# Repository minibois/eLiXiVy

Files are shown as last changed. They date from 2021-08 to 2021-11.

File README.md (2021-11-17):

# mini-eLiXiVy
## Repository for the mini-eLiXiVy, a 65% mechanical keyboard PCB, suitable for ISO and ANSI layouts, USB Type C and a (tactile) rotary encoder.
 This PCB is compatible with KBDFans' 65% low profile case/plate and Cherry MX(-like) keyswitches.
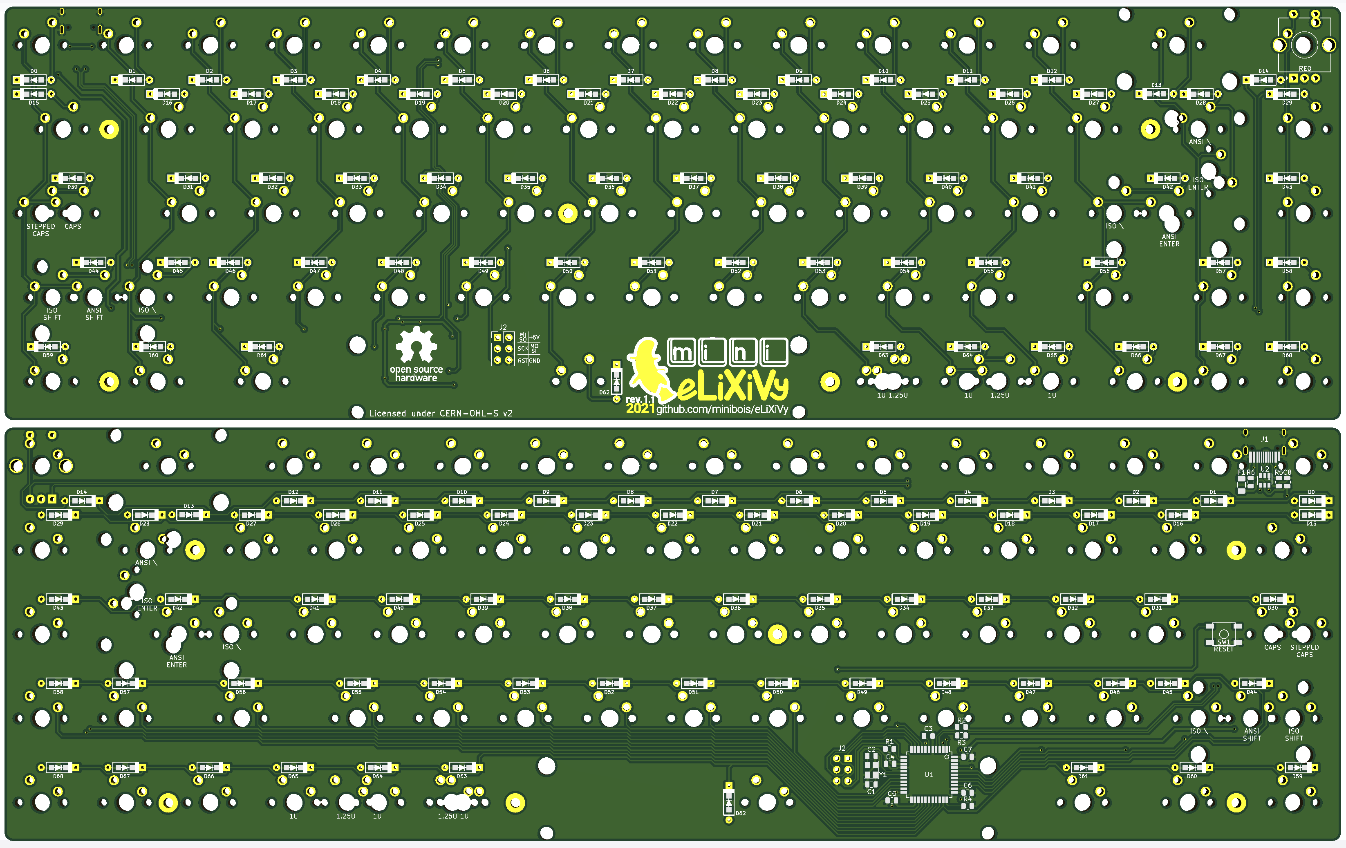
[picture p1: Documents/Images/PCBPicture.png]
mini-eLiXiVy-PCB-Render

 _Render of the front and back of the PCB respectively_

 << [License](https://github.com/minibois/eLiXiVy/blob/master/LICENSE/LICENSE.txt) || [Assembly Guide](https://github.com/minibois/eLiXiVy/blob/master/Documents/Assembly%20Guide.pdf) || BOM ([Octoparts](https://octopart.com/bom-tool/allQRgda)) / ([.txt](https://github.com/minibois/eLiXiVy/blob/master/Documents/BOM.txt)) / ([.xlsx](https://github.com/minibois/eLiXiVy/blob/master/Documents/BOM.xlsx)) || [Supported layouts](https://raw.githubusercontent.com/minibois/eLiXiVy/master/Documents/Layouts/layouts.png) || Schematic ([.pdf](https://github.com/minibois/eLiXiVy/blob/master/Documents/Schematic.pdf)) / ([.sch](https://github.com/minibois/eLiXiVy/blob/master/mini-eLiXiVy.sch)) || PCB ([.pdf](https://github.com/minibois/eLiXiVy/blob/master/Documents/PCB.pdf)) / ([.kicad_pcb](https://github.com/minibois/eLiXiVy/blob/master/mini-eLiXiVy.kicad_pcb)) >>

 The PCB and schematic are licensed under CERN-OHL-S v2, full license details can be found here: https://github.com/minibois/eLiXiVy/blob/master/Documents/LICENSE.txt.

### The compatible layouts for this PCB are as follows:
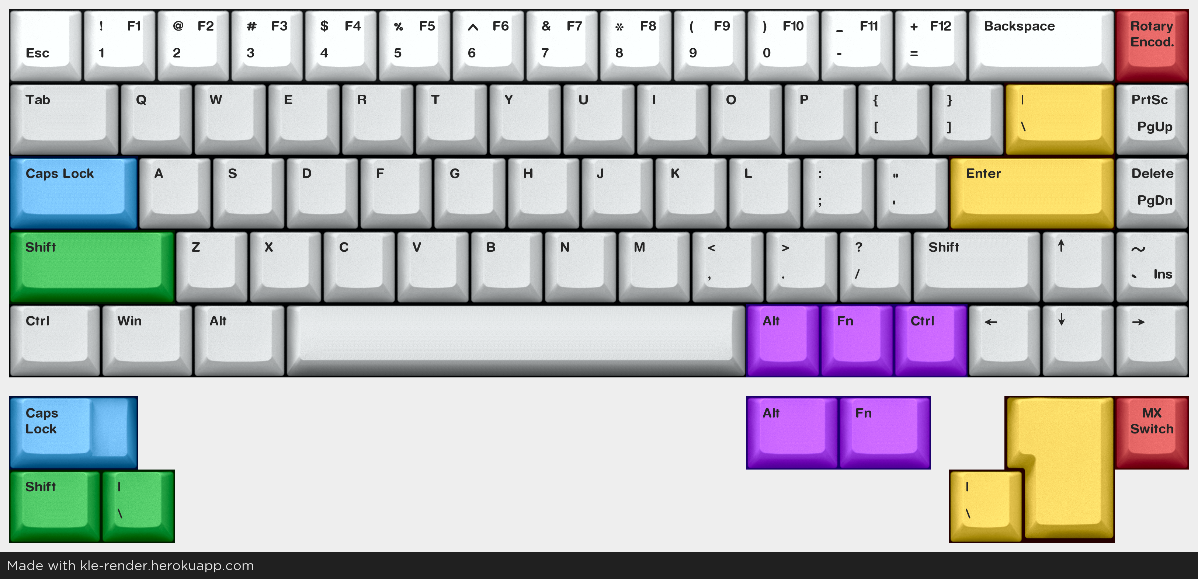
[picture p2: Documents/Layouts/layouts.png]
mini-eLiXiVy-Layouts-Supported

 _The mini-eLiXiVy supports between 66 and 69 switches, depending on the layout chosen._
 In the top right of the keyboard you can either use an MX-like keyswitch or a rotary encoder with switch (see the BOM for a verified compatible option).
 
 While the the bill of materials mentions tested compatible components, substitutes may be available, should these components become difficult to obtain. Should you choose alternatives, you do so at your own risk. I can only vouch for the compability of the listed components.

## Libraries used in this project (most of them adapted to this project):
 * That-Canadian's KiCad_labs (for the D-SOD123_axial-dual): https://github.com/That-Canadian/KiCad_Libs
 * Type-C.Pretty: https://github.com/ai03-2725/Type-C.pretty
 * MX_Alps_Hybrid: https://github.com/ai03-2725/MX_Alps_Hybrid
 * random-keyboard-parts (for a reset switch): https://github.com/ai03-2725/random-keyboard-parts.pretty

### This PCB file and schematic is provided - as per CERN-OHL-S v2 section 6 - _without any warranty_ (implied or otherwise). https://ohwr.org/cern_ohl_s_v2.pdf
### The assembly guide is provided under the CC BY-SA 4.0, without any warranty (implied or otherwise): https://creativecommons.org/licenses/by-sa/4.0/legalcode

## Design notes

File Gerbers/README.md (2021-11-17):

rev.1a is the alpha version of the project, included for completeness sake.
rev.1 had some minor changes
rev.1.1 (or newer) is recommended for assembly

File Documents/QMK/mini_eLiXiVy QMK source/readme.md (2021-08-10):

# mini_eLiXiVy

mini_eLiXiVy

*A short description of the keyboard/project*

* Keyboard Maintainer: [minibois](https://github.com/minibois)
* Hardware Supported: mini_eLiXiVy PCB, KBDFans' 65% plate and case, PCB mount stabilizers
* Hardware Availability: PCB: https://github.com/minibois, BOM: https://octopart.com/bom-tool/allQRgda

Make example for this keyboard (after setting up your build environment):

    make mini_eLiXiVy:default

Flashing example for this keyboard:

    make mini_eLiXiVy:default:flash

See the [build environment setup](https://docs.qmk.fm/#/getting_started_build_tools) and the [make instructions](https://docs.qmk.fm/#/getting_started_make_guide) for more information. 
Brand new to QMK? Start with our [Complete Newbs Guide](https://docs.qmk.fm/#/newbs).

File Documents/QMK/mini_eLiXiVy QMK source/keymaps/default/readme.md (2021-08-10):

# The default keymap for mini_eLiXiVy
This is an ANSI keymap, with three 1u modifiers between the spacebar/arrow keys and a rotary encoder.

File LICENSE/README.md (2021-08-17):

# Copyright minibois 2021.

This source describes Open Hardware and is licensed under the CERN-OHL-S v2.
You may redistribute and modify this source and make products using it under the terms of the CERN-OHL-S v2 (https://ohwr.org/cern_ohl_s_v2.txt).
This source is distributed WITHOUT ANY EXPRESS OR IMPLIED WARRANTY, INCLUDING OF MERCHANTABILITY, SATISFACTORY QUALITY AND FITNESS FOR A PARTICULAR PURPOSE.
Please see the CERN-OHL-S v2 for applicable conditions.

As per CERN-OHL-S v2 section 4, should you produce hardware based on this source, you must where practicable maintain the Source Location visible on the keyboard PCB or on other products you make using this source.
Source location: https://github.com/minibois/eLiXiVy/
When changes have been made, please update ../Documents/CHANGES.txt accordingly.

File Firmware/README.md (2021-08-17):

# mini eLiXiVy firmware files
Depending on the layout chosen for the eLiXiVy, a different firmware version may be suitable.
This folder has three firmware types available: default, ansi and iso.
As a reminder, the eLiXiVy supports these layouts:
mini-eLiXiVy-Layouts-Supported

## Default
This is a barebones firmware with an ansi layout:
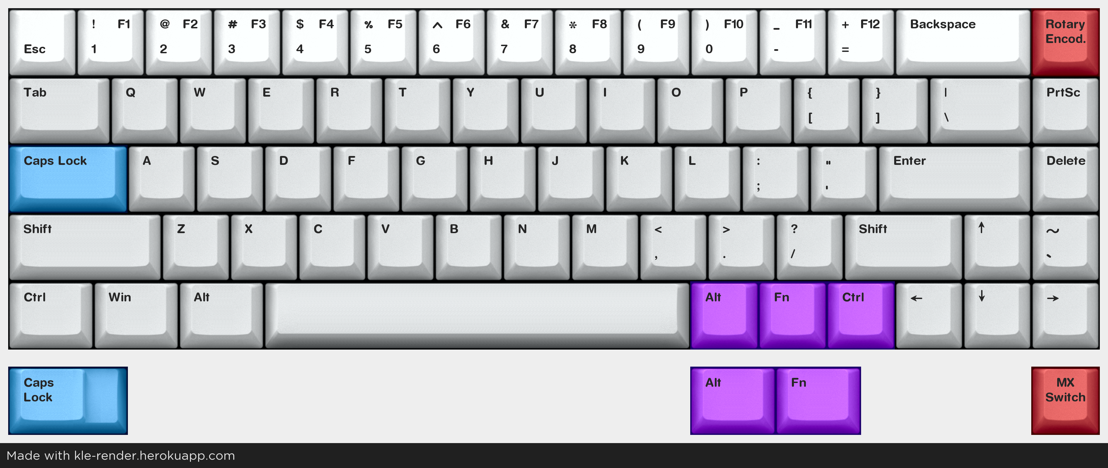
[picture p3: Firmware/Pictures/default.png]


## ansi
This is like the default firmware, but with some added functionality under the Function layer
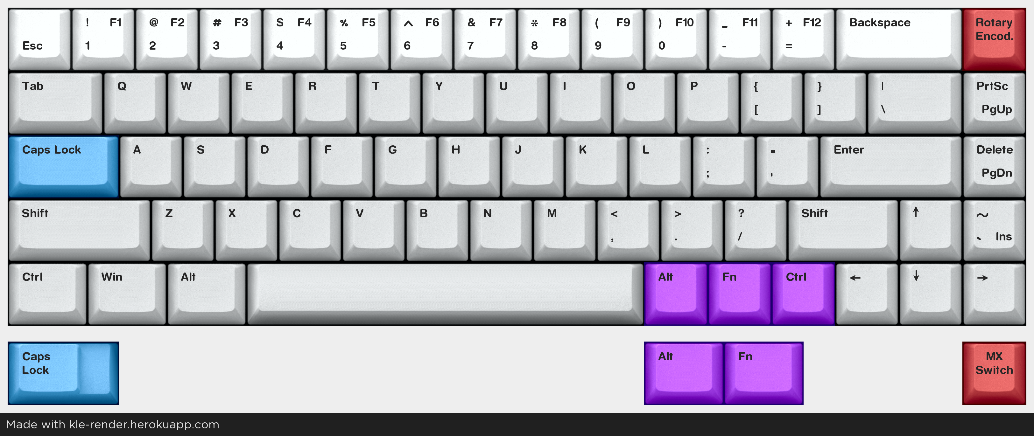
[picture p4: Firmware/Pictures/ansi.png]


## iso
While the default and ansi firmware are both using the ansi layout, the iso firmware uses the iso layout, with its backslash key on the left and iso (upside-down L) Enter.
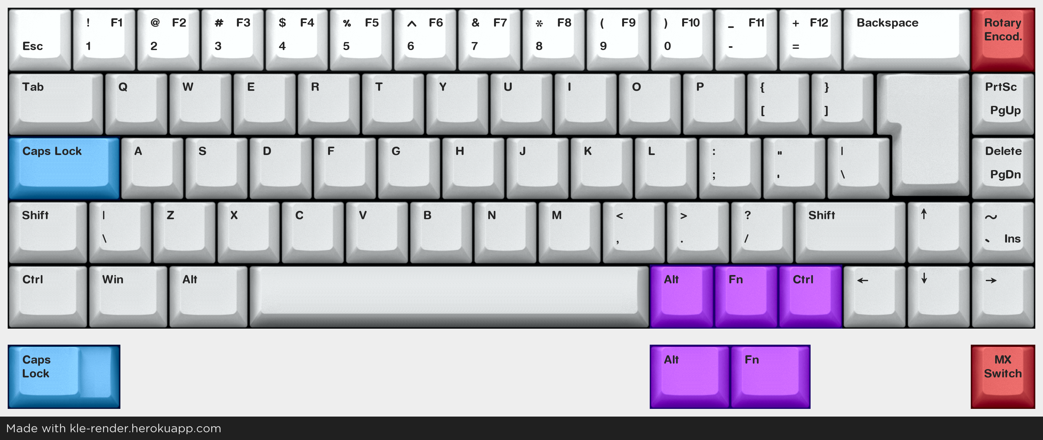
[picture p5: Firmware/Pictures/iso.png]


## Extra options on the firmware versions
Each version of the firmware still has support for a couple different options, such as stepped Caps Lock or not and two or three modifiers between Space and the Arrow Keys. It doesn't matter which of these is used, the firmware will support both.

## Should these firmware versions not work
In the case these firwmare versions don't match your build - either in physical sizes or keycodes - it's possible to edit the keymaps to suit your need.
Refer to the section [6.6] of the Assembly Guide for more information on editing the keymap.

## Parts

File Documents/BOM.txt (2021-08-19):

Qty		Product				Description			Schematic	Notes
1		mini-eLiXiVy PCB		PCB				N/A		To be purchased from your preffered PCB manufacturer
1		ATMEGA32U4-AU			Microcontroller			U1
2  		CL21C220JB61PNC 		0805 22p Capacitor		C1,C2
1		CL21B105KAFNNNE			0805 1u Capacitor		C3
4		CL21B104MBCNNNC			0805 0.1u Capacitor		C4,C5,C6,C8
1		CL21A106KOQNNNG			0805 10u Capacitor		C7
66-69	1N4148					THT Diode				D0-D68	Either this or 1N4148W
66-69	1N4148W					SMD Diode				D0-D68	Either this or 1N4148
1		1206L050/15YR			1206 500mA Fuse			F1
2		ERA-6AEB103V			0805 10K Resistor		R1,R4
2		ERJ-6GEYJ220V			0805 22 Resistor		R2,R3
2		ERJ-6RBD5101V			0805 5.1K Resistor		R5,R6
1		RS187R05A2DSMTRT		Tactile Switch			SW1		Optional, refer to assembly guide
1		TYPE-C-31-M-12			USB Type C				J1
1		82400102				TVS Diode				U2
1		ECS-160-8-33B-CTN-TR	16MHz Crystal			Y1
66-69	MX-Like switches		Switches				MX		Refer to assembly guide and Documents/layouts.png
1		ALP-ENC-IND-000			Rotary Encoder			RE1		Optional, refer to Documents/layouts.png
1		case0026				KBDFans' 65% case		N/A		Confirmed to work, others may apply.
1		PJ0138					KBDFans' 65% plate		N/A		Confirmed to work, others may apply.
1		Stabilizers				6.25u and 2/3x 2u		N/A		2x 2u stabs for ISO, 3x 2u for ANSI. Refer to Assembly Guide
1		Stabilizer Lubricant							N/A 	It's recommended to apply lube to stabs. Refer to Assembly Guide
1		Keycaps					65% Set 				N/A 	Set for your desired layout. Refer to Documents/layouts.png
1 		USB Type C cable								N/A 	Cable to connect the keyboard
N/A    	TOOLS/Supplies									N/A 	For a list of required tools/supplies, refer to the Assembly Guide.

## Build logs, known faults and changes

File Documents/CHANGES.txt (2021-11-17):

2021-07-13: CHANGES.txt made.
This file can be used to document any change(s) made to this open source project, as per 3.1.2 of the CERN-OHL-S v2 User Guide.
Please use the YYYY-MM-DD date format (ISO 8601) and list the modification(s) made.

2021-10-17: Release of rev.1.1
Upon reflecting on the build process and releasing the build log online, rev.1.1 was released.

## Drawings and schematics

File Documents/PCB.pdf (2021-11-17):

mini-eLiXiVy, PCB.

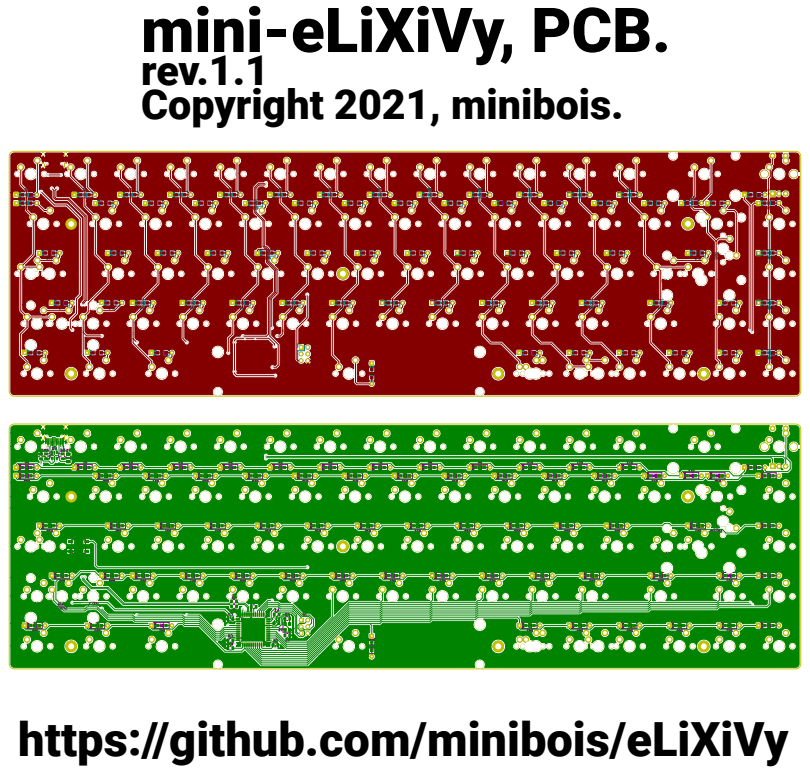
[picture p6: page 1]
rev.1.1 Copyright 2021, minibois.

https://github.com/minibois/eLiXiVy

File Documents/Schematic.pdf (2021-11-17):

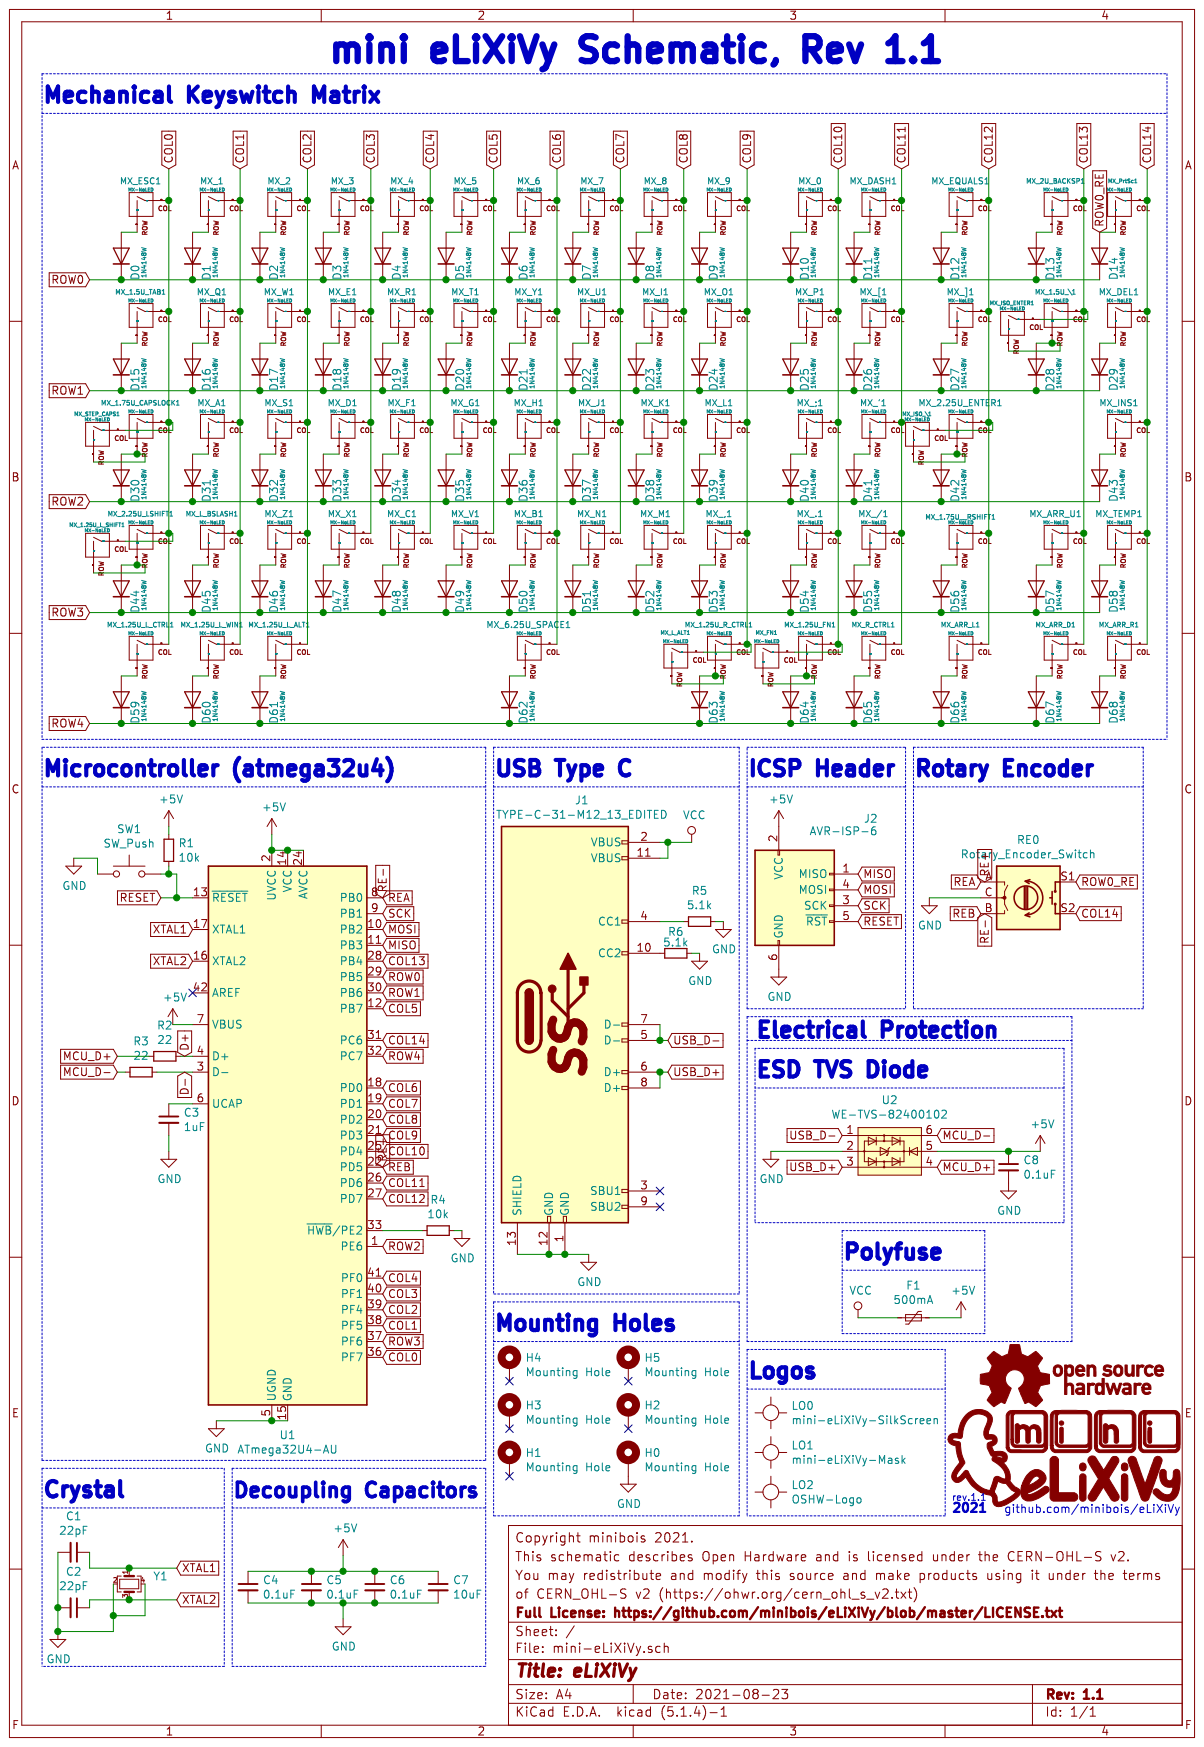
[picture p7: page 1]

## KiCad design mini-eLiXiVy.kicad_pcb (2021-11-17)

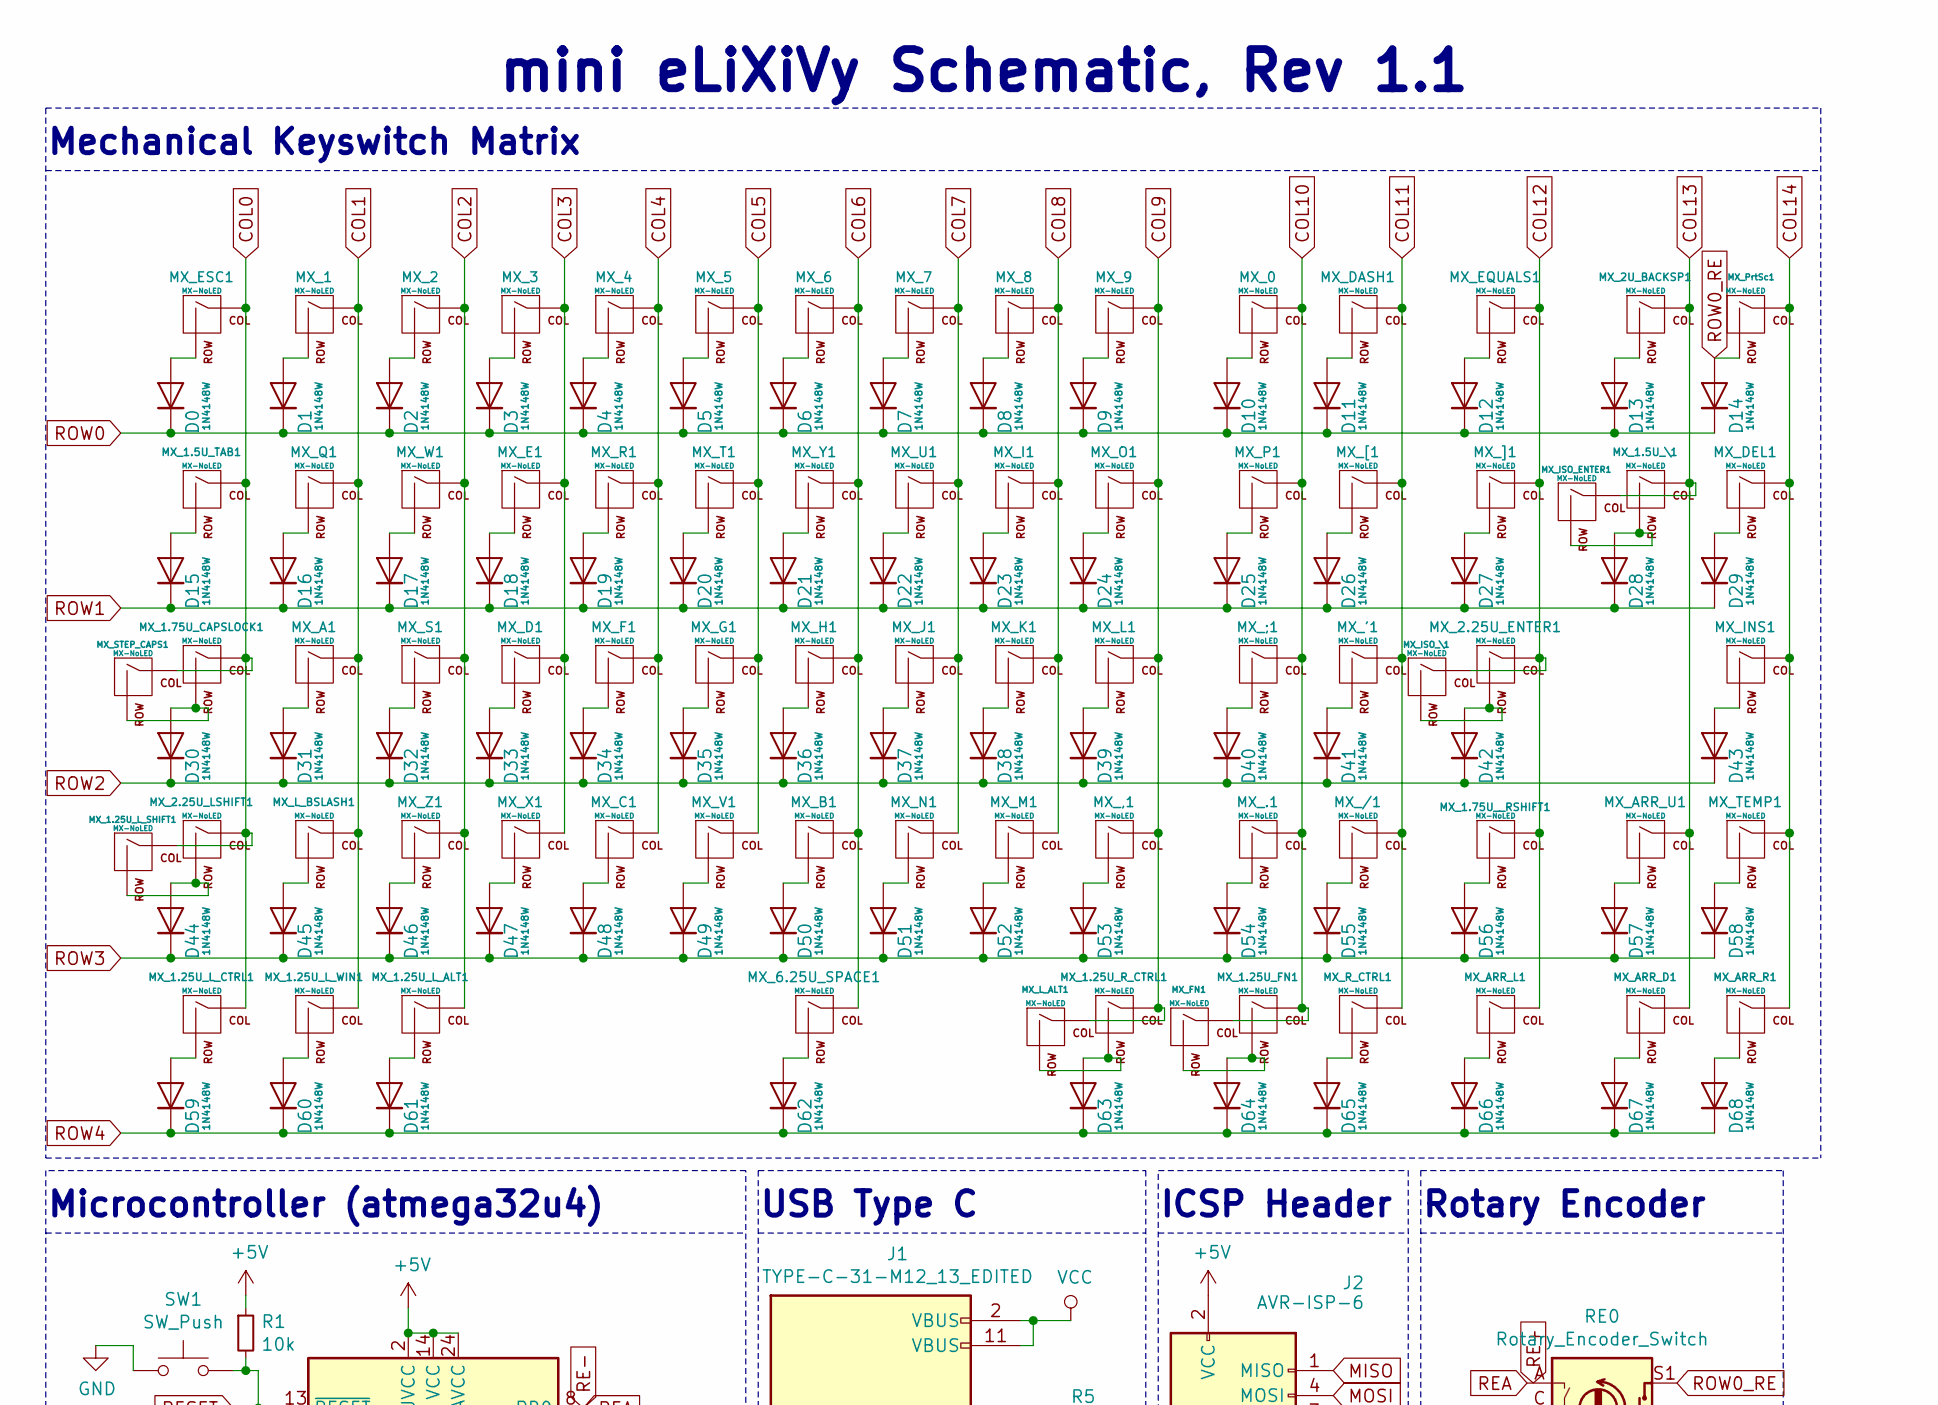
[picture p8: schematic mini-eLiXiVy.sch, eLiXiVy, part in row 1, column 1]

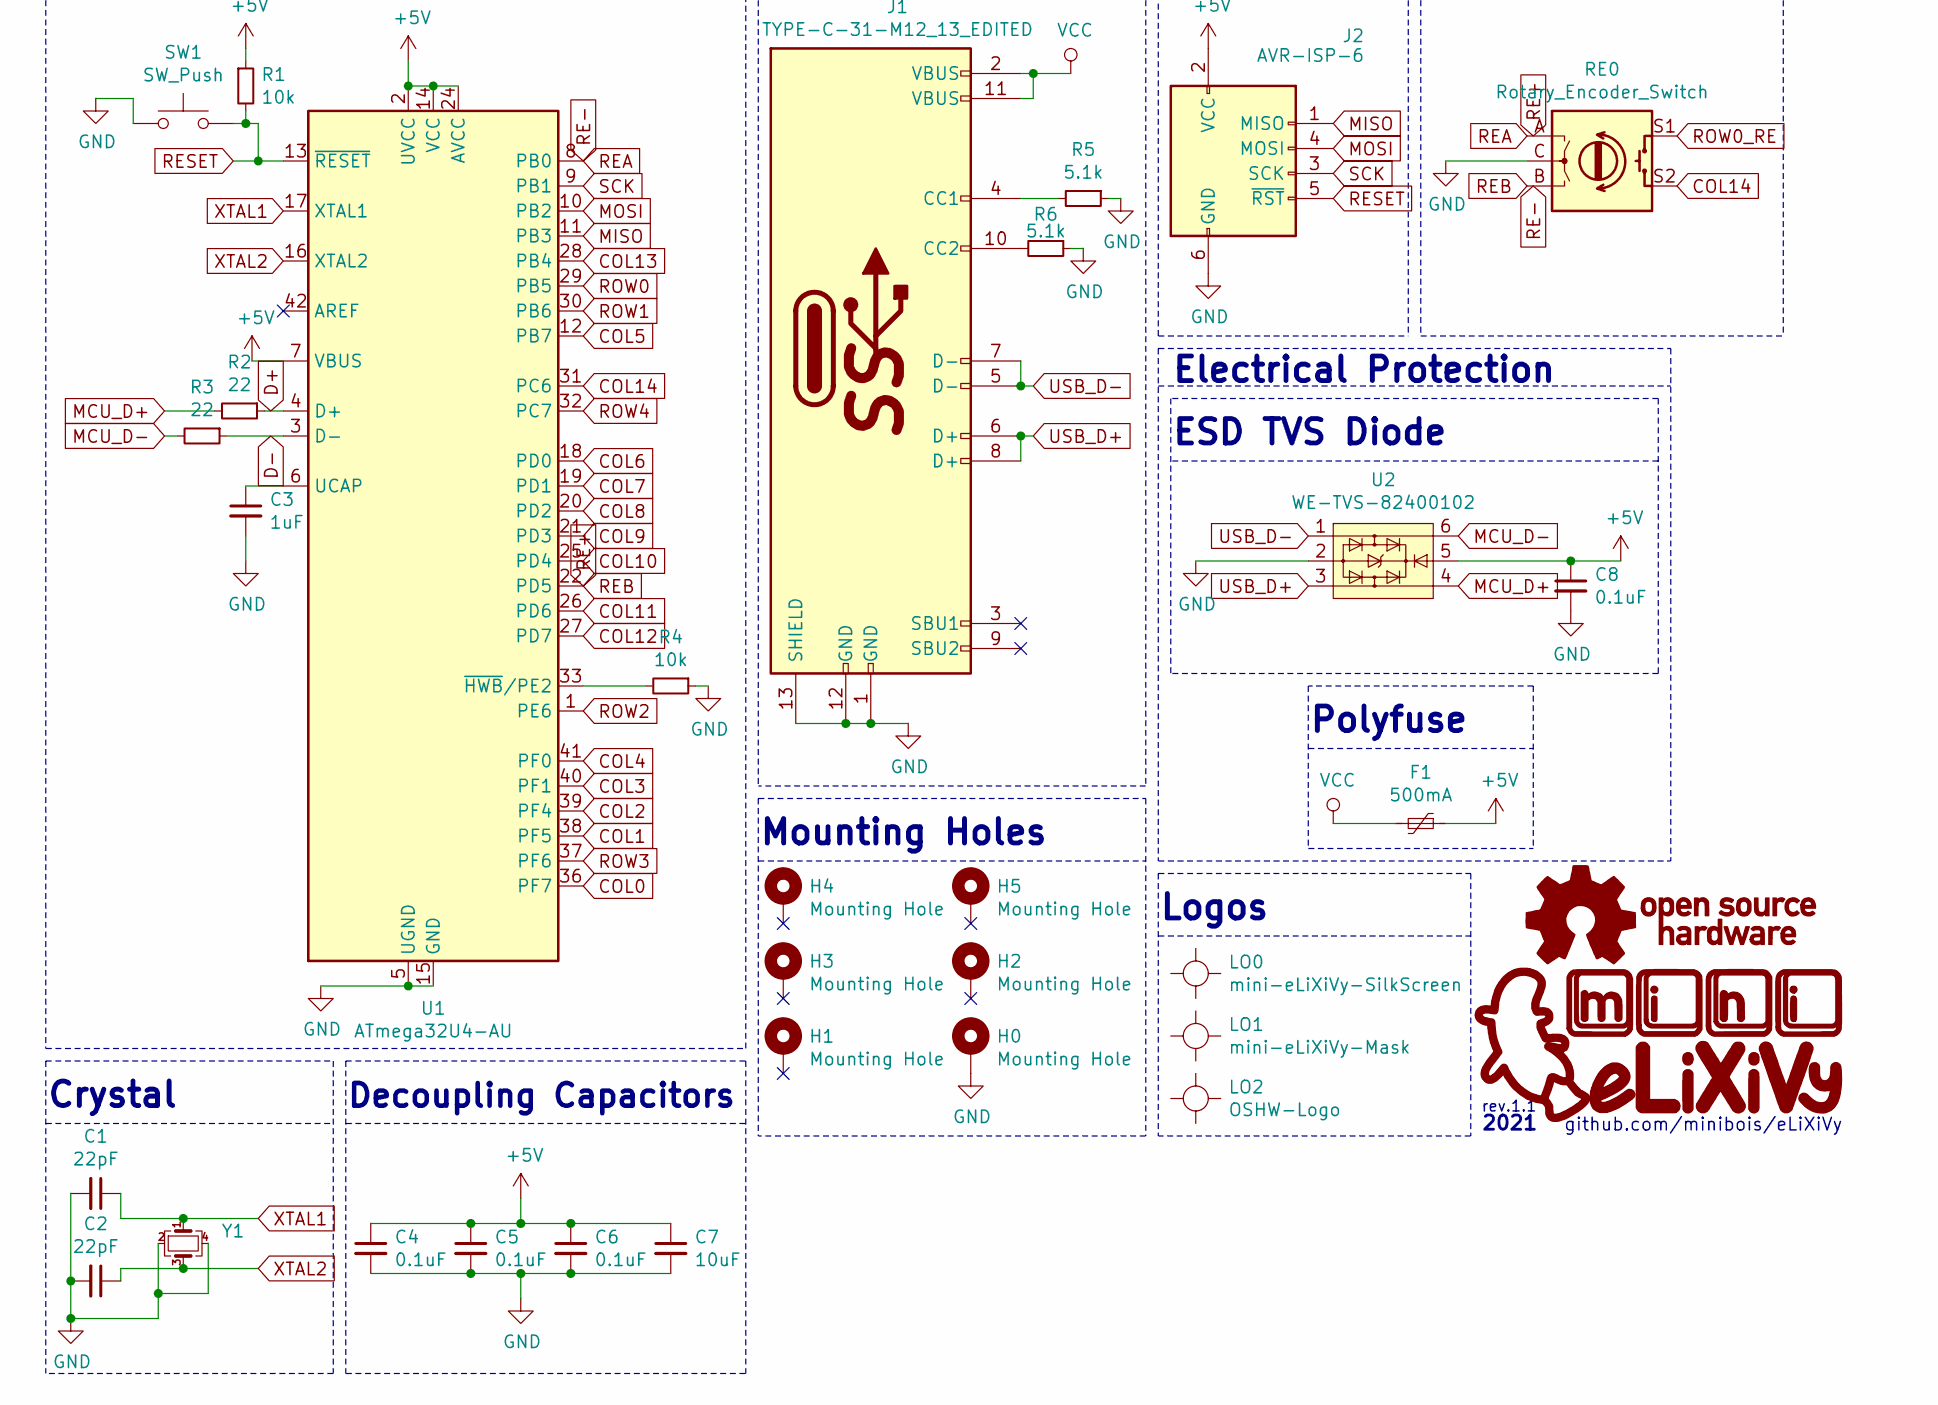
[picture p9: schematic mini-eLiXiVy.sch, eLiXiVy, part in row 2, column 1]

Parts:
C1, C2: 22pF; C_0805_2012Metric
C3: 1uF; C_0805_2012Metric
C4, C5, C6, C8: 0.1uF; C_0805_2012Metric
C7: 10uF; C_0805_2012Metric
D0, D1, D2, D3, D4, D5, D6, D7, D8, D9, D10, D11, D12, D13, D14, D15, D16, D17, D18, D19, D20, D21, D22, D23, D24, D25, D26, D27, D28, D29, D30, D31, D32, D33, D34, D35, D36, D37, D38, D39, D40, D41, D42, D43, D44, D45, D46, D47, D48, D49, D50, D51, D52, D53, D54, D55, D56, D57, D58, D59, D60, D61, D62, D63, D64, D65, D66, D67, D68: 1N4148W; D_SOD123_axial-dual
F1: 500mA; Fuse_1206_3216Metric
H0, H1, H2, H3, H4, H5: Mounting Hole; MountingHole_2.2mm_M2_Pad_tweaked
J1: TYPE-C-31-M12_13_EDITED; HRO-TYPE-C-31-M-12-HandSoldering_tweaked
J2: AVR-ISP-6; ICSP_2.54mm_LAYOUT
LO0: mini-eLiXiVy-SilkScreen; eLiXiVy-rev1.1-SilkScreen
LO1: mini-eLiXiVy-Mask; eLiXiVy-rev1.1-Mask
LO2: OSHW-Logo
MX_0, MX_1, MX_2, MX_3, MX_4, MX_5, MX_6, MX_7, MX_8, MX_9, MX_.1: MX-NoLED; MXOnly-1U-NoLED_tweak
MX_1.5U_TAB1, MX_1.5U_\1: MX-NoLED; MXOnly-1.5U-NoLED_tweak
MX_1.25U_FN1, MX_1.25U_L_ALT1, MX_1.25U_L_CTRL1, MX_1.25U_L_SHIFT1, MX_1.25U_L_WIN1, MX_1.25U_R_CTRL1: MX-NoLED; MXOnly-1.25U-NoLED_tweak
MX_1.75U_CAPSLOCK1, MX_1.75U__RSHIFT1: MX-NoLED; MXOnly-1.75U-NoLED_tweak
MX_2.25U_ENTER1, MX_2.25U_LSHIFT1: MX-NoLED; MXOnly-2.25U-NoLED_tweak
MX_2U_BACKSP1: MX-NoLED; MXOnly-2U-NoLED_tweak
MX_6.25U_SPACE1: MX-NoLED; MXOnly-6.25U-ReversedStabilizers-NoLED_tweak
MX_'1: MX-NoLED; MXOnly-1U-NoLED_tweak
MX_,1: MX-NoLED; MXOnly-1U-NoLED_tweak
MX_/1: MX-NoLED; MXOnly-1U-NoLED_tweak
MX_;1: MX-NoLED; MXOnly-1U-NoLED_tweak
MX_A1: MX-NoLED; MXOnly-1U-NoLED_tweak
MX_ARR_D1: MX-NoLED; MXOnly-1U-NoLED_tweak
MX_ARR_L1: MX-NoLED; MXOnly-1U-NoLED_tweak
MX_ARR_R1: MX-NoLED; MXOnly-1U-NoLED_tweak
MX_ARR_U1: MX-NoLED; MXOnly-1U-NoLED_tweak
MX_B1: MX-NoLED; MXOnly-1U-NoLED_tweak
MX_C1: MX-NoLED; MXOnly-1U-NoLED_tweak
MX_D1: MX-NoLED; MXOnly-1U-NoLED_tweak
MX_DASH1: MX-NoLED; MXOnly-1U-NoLED_tweak
MX_DEL1: MX-NoLED; MXOnly-1U-NoLED_tweak
MX_E1: MX-NoLED; MXOnly-1U-NoLED_tweak
MX_EQUALS1: MX-NoLED; MXOnly-1U-NoLED_tweak
MX_ESC1: MX-NoLED; MXOnly-1U-NoLED_tweak
MX_F1: MX-NoLED; MXOnly-1U-NoLED_tweak
MX_FN1: MX-NoLED; MXOnly-1U-NoLED_tweak
MX_G1: MX-NoLED; MXOnly-1U-NoLED_tweak
MX_H1: MX-NoLED; MXOnly-1U-NoLED_tweak
MX_I1: MX-NoLED; MXOnly-1U-NoLED_tweak
MX_INS1: MX-NoLED; MXOnly-1U-NoLED_tweak
MX_ISO_ENTER1: MX-NoLED; MXOnly-ISO-ROTATED-ReversedStabilizers-NoLED_tweak
MX_ISO_\1: MX-NoLED; MXOnly-1U-NoLED_tweak
MX_J1: MX-NoLED; MXOnly-1U-NoLED_tweak
MX_K1: MX-NoLED; MXOnly-1U-NoLED_tweak
MX_L1: MX-NoLED; MXOnly-1U-NoLED_tweak
MX_L_ALT1: MX-NoLED; MXOnly-1U-NoLED_tweak
MX_L_BSLASH1: MX-NoLED; MXOnly-1U-NoLED_tweak
MX_M1: MX-NoLED; MXOnly-1U-NoLED_tweak
MX_N1: MX-NoLED; MXOnly-1U-NoLED_tweak
MX_O1: MX-NoLED; MXOnly-1U-NoLED_tweak
MX_P1: MX-NoLED; MXOnly-1U-NoLED_tweak
MX_PrtSc1: MX-NoLED; MXOnly-1U-NoLED_tweak
MX_Q1: MX-NoLED; MXOnly-1U-NoLED_tweak
MX_R1: MX-NoLED; MXOnly-1U-NoLED_tweak
MX_R_CTRL1: MX-NoLED; MXOnly-1U-NoLED_tweak
MX_S1: MX-NoLED; MXOnly-1U-NoLED_tweak
MX_STEP_CAPS1: MX-NoLED; MXOnly-1U-NoLED_tweak
MX_T1: MX-NoLED; MXOnly-1U-NoLED_tweak
MX_TEMP1: MX-NoLED; MXOnly-1U-NoLED_tweak
MX_U1: MX-NoLED; MXOnly-1U-NoLED_tweak
MX_V1: MX-NoLED; MXOnly-1U-NoLED_tweak
MX_W1: MX-NoLED; MXOnly-1U-NoLED_tweak
MX_X1: MX-NoLED; MXOnly-1U-NoLED_tweak
MX_Y1: MX-NoLED; MXOnly-1U-NoLED_tweak
MX_Z1: MX-NoLED; MXOnly-1U-NoLED_tweak
MX_[1: MX-NoLED; MXOnly-1U-NoLED_tweak
MX_]1: MX-NoLED; MXOnly-1U-NoLED_tweak
R1, R4: 10k; R_0805_2012Metric
R2, R3: 22; R_0805_2012Metric
R5, R6: 5.1k; R_0805_2012Metric
RE0: Rotary_Encoder_Switch; RotaryEncoder_Alps_EC11E-Switch-Vertical-EDIT
SW1: SW_Push; SKQG-1155865
U1: ATmega32U4-AU; TQFP-44_10x10mm_P0.8mm_ATmega32U4
U2: WE-TVS-82400102; SOT-23-6_tweaked
Y1: Crystal_GND24_Small; Crystal_SMD_3225-4Pin_3.2x2.5mm

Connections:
+5V: C4.1, C5.1, C6.1, C7.1, C8.1, F1.1, J2.2 (VCC), R1.1, U1.2 (UVCC), U1.7 (VBUS), U1.14 (VCC), U1.24 (AVCC), U1.34 (VCC), U1.44 (AVCC), U2.5
COL0: MX_1.5U_TAB1.1 (COL), MX_1.25U_L_CTRL1.1 (COL), MX_1.25U_L_SHIFT1.1 (COL), MX_1.75U_CAPSLOCK1.1 (COL), MX_2.25U_LSHIFT1.1 (COL), MX_ESC1.1 (COL), MX_STEP_CAPS1.1 (COL), U1.36 (PF7)
COL1: MX_1.1 (COL), MX_1.25U_L_WIN1.1 (COL), MX_A1.1 (COL), MX_L_BSLASH1.1 (COL), MX_Q1.1 (COL), U1.38 (PF5)
COL2: MX_1.25U_L_ALT1.1 (COL), MX_2.1 (COL), MX_S1.1 (COL), MX_W1.1 (COL), MX_Z1.1 (COL), U1.39 (PF4)
COL3: MX_3.1 (COL), MX_D1.1 (COL), MX_E1.1 (COL), MX_X1.1 (COL), U1.40 (PF1)
COL4: MX_4.1 (COL), MX_C1.1 (COL), MX_F1.1 (COL), MX_R1.1 (COL), U1.41 (PF0)
COL5: MX_5.1 (COL), MX_G1.1 (COL), MX_T1.1 (COL), MX_V1.1 (COL), U1.12 (PB7)
COL6: MX_6.1 (COL), MX_6.25U_SPACE1.1 (COL), MX_B1.1 (COL), MX_H1.1 (COL), MX_Y1.1 (COL), U1.18 (PD0)
COL7: MX_7.1 (COL), MX_J1.1 (COL), MX_N1.1 (COL), MX_U1.1 (COL), U1.19 (PD1)
COL8: MX_8.1 (COL), MX_I1.1 (COL), MX_K1.1 (COL), MX_M1.1 (COL), U1.20 (PD2)
COL9: MX_1.25U_R_CTRL1.1 (COL), MX_9.1 (COL), MX_,1.1 (COL), MX_L1.1 (COL), MX_L_ALT1.1 (COL), MX_O1.1 (COL), U1.21 (PD3)
COL10: MX_0.1 (COL), MX_1.25U_FN1.1 (COL), MX_.1.1 (COL), MX_;1.1 (COL), MX_FN1.1 (COL), MX_P1.1 (COL), U1.25 (PD4)
COL11: MX_'1.1 (COL), MX_/1.1 (COL), MX_DASH1.1 (COL), MX_R_CTRL1.1 (COL), MX_[1.1 (COL), U1.26 (PD6)
COL12: MX_1.75U__RSHIFT1.1 (COL), MX_2.25U_ENTER1.1 (COL), MX_ARR_L1.1 (COL), MX_EQUALS1.1 (COL), MX_ISO_\1.1 (COL), MX_]1.1 (COL), U1.27 (PD7)
COL13: MX_1.5U_\1.1 (COL), MX_2U_BACKSP1.1 (COL), MX_ARR_D1.1 (COL), MX_ARR_U1.1 (COL), MX_ISO_ENTER1.1 (COL), U1.28 (PB4)
COL14: MX_ARR_R1.1 (COL), MX_DEL1.1 (COL), MX_INS1.1 (COL), MX_PrtSc1.1 (COL), MX_TEMP1.1 (COL), RE0.S2, U1.31 (PC6)
D+: R2.1, U1.4 (D+)
D-: R3.1, U1.3 (D-)
GND: C1.2, C2.2, C3.2, C4.2, C5.2, C6.2, C7.2, C8.2, H0.1, J1.1 (GND), J1.12 (GND), J1.13 (SHIELD), J2.6 (GND), R4.1, R5.1, R6.1, RE0.C, SW1.1, U1.5 (UGND), U1.15 (GND), U1.23 (GND), U1.35 (GND), U1.43 (GND), U2.2, Y1.2, Y1.4
MCU_D+: R2.2, U2.4
MCU_D-: R3.2, U2.6
MISO: J2.1 (MISO), U1.11 (PB3)
MOSI: J2.4 (MOSI), U1.10 (PB2)
unnamed: C3.1, U1.6 (UCAP)
unnamed: D0.2 (A), MX_ESC1.2 (ROW)
unnamed: D1.2 (A), MX_1.2 (ROW)
unnamed: D2.2 (A), MX_2.2 (ROW)
unnamed: D3.2 (A), MX_3.2 (ROW)
unnamed: D4.2 (A), MX_4.2 (ROW)
unnamed: D5.2 (A), MX_5.2 (ROW)
unnamed: D6.2 (A), MX_6.2 (ROW)
unnamed: D7.2 (A), MX_7.2 (ROW)
unnamed: D8.2 (A), MX_8.2 (ROW)
unnamed: D9.2 (A), MX_9.2 (ROW)
unnamed: D10.2 (A), MX_0.2 (ROW)
unnamed: D11.2 (A), MX_DASH1.2 (ROW)
unnamed: D12.2 (A), MX_EQUALS1.2 (ROW)
unnamed: D13.2 (A), MX_2U_BACKSP1.2 (ROW)
unnamed: D15.2 (A), MX_1.5U_TAB1.2 (ROW)
unnamed: D16.2 (A), MX_Q1.2 (ROW)
unnamed: D17.2 (A), MX_W1.2 (ROW)
unnamed: D18.2 (A), MX_E1.2 (ROW)
unnamed: D19.2 (A), MX_R1.2 (ROW)
unnamed: D20.2 (A), MX_T1.2 (ROW)
unnamed: D21.2 (A), MX_Y1.2 (ROW)
unnamed: D22.2 (A), MX_U1.2 (ROW)
unnamed: D23.2 (A), MX_I1.2 (ROW)
unnamed: D24.2 (A), MX_O1.2 (ROW)
unnamed: D25.2 (A), MX_P1.2 (ROW)
unnamed: D26.2 (A), MX_[1.2 (ROW)
unnamed: D27.2 (A), MX_]1.2 (ROW)
unnamed: D28.2 (A), MX_1.5U_\1.2 (ROW), MX_ISO_ENTER1.2 (ROW)
unnamed: D29.2 (A), MX_DEL1.2 (ROW)
unnamed: D30.2 (A), MX_1.75U_CAPSLOCK1.2 (ROW), MX_STEP_CAPS1.2 (ROW)
unnamed: D31.2 (A), MX_A1.2 (ROW)
unnamed: D32.2 (A), MX_S1.2 (ROW)
unnamed: D33.2 (A), MX_D1.2 (ROW)
unnamed: D34.2 (A), MX_F1.2 (ROW)
unnamed: D35.2 (A), MX_G1.2 (ROW)
unnamed: D36.2 (A), MX_H1.2 (ROW)
unnamed: D37.2 (A), MX_J1.2 (ROW)
unnamed: D38.2 (A), MX_K1.2 (ROW)
unnamed: D39.2 (A), MX_L1.2 (ROW)
unnamed: D40.2 (A), MX_;1.2 (ROW)
unnamed: D41.2 (A), MX_'1.2 (ROW)
unnamed: D42.2 (A), MX_2.25U_ENTER1.2 (ROW), MX_ISO_\1.2 (ROW)
unnamed: D43.2 (A), MX_INS1.2 (ROW)
unnamed: D44.2 (A), MX_1.25U_L_SHIFT1.2 (ROW), MX_2.25U_LSHIFT1.2 (ROW)
unnamed: D45.2 (A), MX_L_BSLASH1.2 (ROW)
unnamed: D46.2 (A), MX_Z1.2 (ROW)
unnamed: D47.2 (A), MX_X1.2 (ROW)
unnamed: D48.2 (A), MX_C1.2 (ROW)
unnamed: D49.2 (A), MX_V1.2 (ROW)
unnamed: D50.2 (A), MX_B1.2 (ROW)
unnamed: D51.2 (A), MX_N1.2 (ROW)
unnamed: D52.2 (A), MX_M1.2 (ROW)
unnamed: D53.2 (A), MX_,1.2 (ROW)
unnamed: D54.2 (A), MX_.1.2 (ROW)
unnamed: D55.2 (A), MX_/1.2 (ROW)
unnamed: D56.2 (A), MX_1.75U__RSHIFT1.2 (ROW)
unnamed: D57.2 (A), MX_ARR_U1.2 (ROW)
unnamed: D58.2 (A), MX_TEMP1.2 (ROW)
unnamed: D59.2 (A), MX_1.25U_L_CTRL1.2 (ROW)
unnamed: D60.2 (A), MX_1.25U_L_WIN1.2 (ROW)
unnamed: D61.2 (A), MX_1.25U_L_ALT1.2 (ROW)
unnamed: D62.2 (A), MX_6.25U_SPACE1.2 (ROW)
unnamed: D63.2 (A), MX_1.25U_R_CTRL1.2 (ROW), MX_L_ALT1.2 (ROW)
unnamed: D64.2 (A), MX_1.25U_FN1.2 (ROW), MX_FN1.2 (ROW)
unnamed: D65.2 (A), MX_R_CTRL1.2 (ROW)
unnamed: D66.2 (A), MX_ARR_L1.2 (ROW)
unnamed: D67.2 (A), MX_ARR_D1.2 (ROW)
unnamed: D68.2 (A), MX_ARR_R1.2 (ROW)
unnamed: J1.4 (CC1), R5.2
unnamed: J1.10 (CC2), R6.2
unnamed: R4.2, U1.33 (~HWB~/PE2)
RE+: RE0.B, U1.22 (PD5)
RE-: RE0.A, U1.8 (PB0)
RESET: J2.5 (~RST), R1.2, SW1.2, U1.13 (~RESET)
ROW0: D0.1 (K), D1.1 (K), D2.1 (K), D3.1 (K), D4.1 (K), D5.1 (K), D6.1 (K), D7.1 (K), D8.1 (K), D9.1 (K), D10.1 (K), D11.1 (K), D12.1 (K), D13.1 (K), D14.1 (K), U1.29 (PB5)
ROW0_RE: D14.2 (A), MX_PrtSc1.2 (ROW), RE0.S1
ROW1: D15.1 (K), D16.1 (K), D17.1 (K), D18.1 (K), D19.1 (K), D20.1 (K), D21.1 (K), D22.1 (K), D23.1 (K), D24.1 (K), D25.1 (K), D26.1 (K), D27.1 (K), D28.1 (K), D29.1 (K), U1.30 (PB6)
ROW2: D30.1 (K), D31.1 (K), D32.1 (K), D33.1 (K), D34.1 (K), D35.1 (K), D36.1 (K), D37.1 (K), D38.1 (K), D39.1 (K), D40.1 (K), D41.1 (K), D42.1 (K), D43.1 (K), U1.1 (PE6)
ROW3: D44.1 (K), D45.1 (K), D46.1 (K), D47.1 (K), D48.1 (K), D49.1 (K), D50.1 (K), D51.1 (K), D52.1 (K), D53.1 (K), D54.1 (K), D55.1 (K), D56.1 (K), D57.1 (K), D58.1 (K), U1.37 (PF6)
ROW4: D59.1 (K), D60.1 (K), D61.1 (K), D62.1 (K), D63.1 (K), D64.1 (K), D65.1 (K), D66.1 (K), D67.1 (K), D68.1 (K), U1.32 (PC7)
SCK: J2.3 (SCK), U1.9 (PB1)
USB_D+: J1.6 (D+), J1.8 (D+), U2.3
USB_D-: J1.5 (D-), J1.7 (D-), U2.1
VCC: F1.2, J1.2 (VBUS), J1.11 (VBUS)
XTAL1: C1.1, U1.17 (XTAL1), Y1.1
XTAL2: C2.1, U1.16 (XTAL2), Y1.3

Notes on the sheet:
Decoupling Capacitors
Crystal
Mechanical Keyswitch Matrix
mini eLiXiVy Schematic, Rev 1.1
USB Type C
Mounting Holes
Electrical Protection
ESD TVS Diode
Polyfuse
Rotary Encoder
ICSP Header
Logos
github.com/minibois/eLiXiVy
rev.1.1
2021
Microcontroller (atmega32u4)

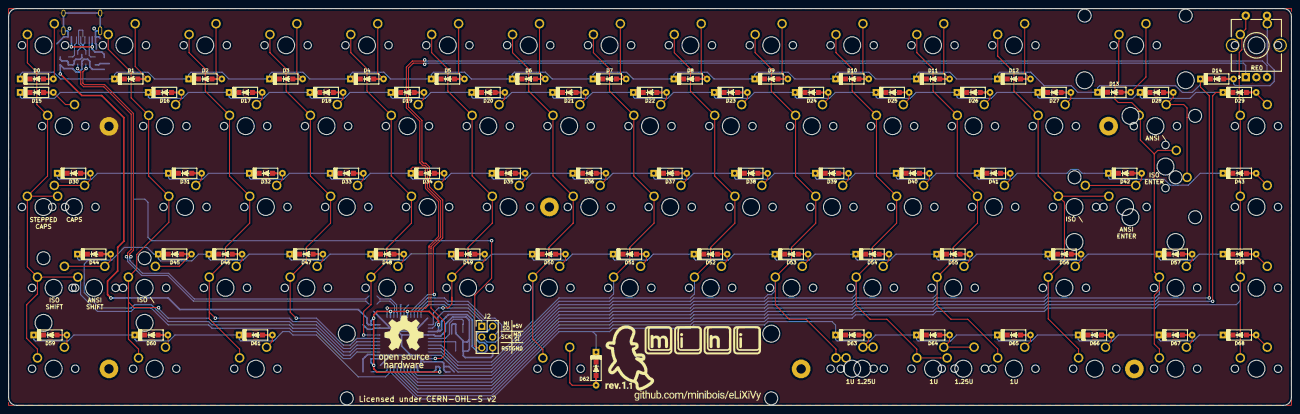
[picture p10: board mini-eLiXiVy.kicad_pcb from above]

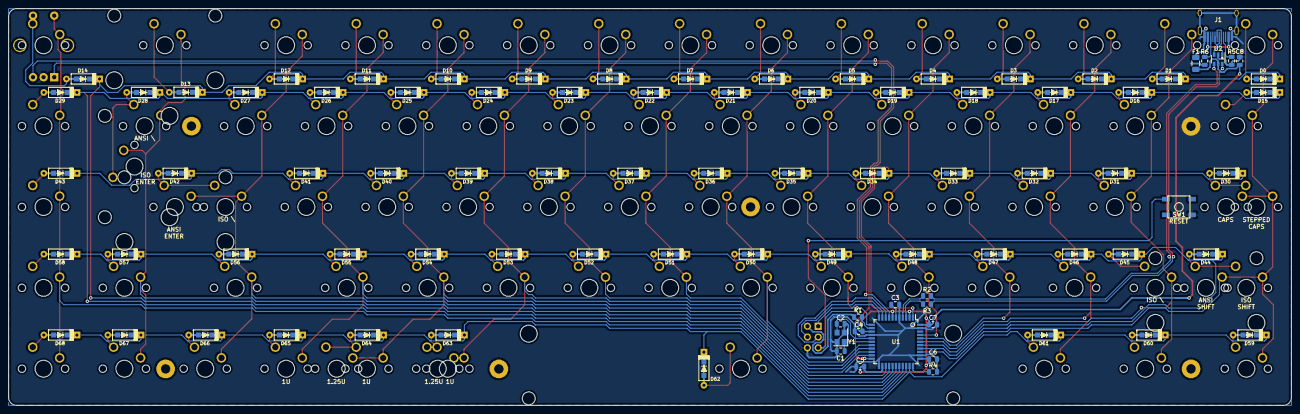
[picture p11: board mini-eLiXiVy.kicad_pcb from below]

Board: 2 copper layers, 302.2 x 93.5 mm, 175 parts (20 on the bottom side), 110 nets.

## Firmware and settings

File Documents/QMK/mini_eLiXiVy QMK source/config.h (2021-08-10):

/*
Copyright 2021 minibois

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
You should have received a copy of the GNU General Public License
along with this program.  If not, see <http://www.gnu.org/licenses/>.
*/

#pragma once

#include "config_common.h"

/* USB Device descriptor parameter */
#define VENDOR_ID    0xFEED
#define PRODUCT_ID   0x0000
#define DEVICE_VER   0x0001
#define MANUFACTURER minibois
#define PRODUCT      mini_eLiXiVy

/* key matrix size */
#define MATRIX_ROWS 5
#define MATRIX_COLS 15

/*
 * Keyboard Matrix Assignments
 *
 * Change this to how you wired your keyboard
 * COLS: AVR pins used for columns, left to right
 * ROWS: AVR pins used for rows, top to bottom
 * DIODE_DIRECTION: COL2ROW = COL = Anode (+), ROW = Cathode (-, marked on diode)
 *                  ROW2COL = ROW = Anode (+), COL = Cathode (-, marked on diode)
 *
 */
#define MATRIX_ROW_PINS { B5, B6, E6, F6, C7 }
#define MATRIX_COL_PINS { F7, F5, F4, F1, F0, B7, D0, D1, D2, D3, D4, D6, D7, B4, C6 }
#define ENCODERS_PAD_A { B0 }
#define ENCODERS_PAD_B { D5 }
#define ENCODER_RESOLUTION 4
/* Turn on, if the encoder's action should be flipped */
//#define ENCODER_DIRECTION_FLIP
#define UNUSED_PINS

/* COL2ROW, ROW2COL */
#define DIODE_DIRECTION COL2ROW

/* Debounce reduces chatter (unintended double-presses) - set 0 if debouncing is not needed */
#define DEBOUNCE 5

/* Mechanical locking support. Use KC_LCAP, KC_LNUM or KC_LSCR instead in keymap */
#define LOCKING_SUPPORT_ENABLE
/* Locking resynchronize hack */
#define LOCKING_RESYNC_ENABLE

/* If defined, GRAVE_ESC will always act as ESC when CTRL is held.
 * This is useful for the Windows task manager shortcut (ctrl+shift+esc).
 */
//#define GRAVE_ESC_CTRL_OVERRIDE

/*
 * Force NKRO
 *
 * Force NKRO (nKey Rollover) to be enabled by default, regardless of the saved
 * state in the bootmagic EEPROM settings. (Note that NKRO must be enabled in the
 * makefile for this to work.)
 *
 * If forced on, NKRO can be disabled via magic key (default = LShift+RShift+N)
 * until the next keyboard reset.
 *
 * NKRO may prevent your keystrokes from being detected in the BIOS, but it is
 * fully operational during normal computer usage.
 *
 * For a less heavy-handed approach, enable NKRO via magic key (LShift+RShift+N)
 * or via bootmagic (hold SPACE+N while plugging in the keyboard). Once set by
 * bootmagic, NKRO mode will always be enabled until it is toggled again during a
 * power-up.
 *
 */
//#define FORCE_NKRO

/*
 * Feature disable options
 *  These options are also useful to firmware size reduction.
 */

/* disable debug print */
//#define NO_DEBUG

/* disable print */
//#define NO_PRINT

/* disable action features */
//#define NO_ACTION_LAYER
//#define NO_ACTION_TAPPING
//#define NO_ACTION_ONESHOT

/* disable these deprecated features by default */
#define NO_ACTION_MACRO
#define NO_ACTION_FUNCTION

/* Bootmagic Lite key configuration */
//#define BOOTMAGIC_LITE_ROW 0
//#define BOOTMAGIC_LITE_COLUMN 0

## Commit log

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2020-07-21 Layed out most the schematic, sans ROW/COL nets
    [mini-65.sch]
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2020-07-22 Moved around alternative keys in schematic to make it easier to read
    [mini-65.sch]
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2020-07-22 Applied some footprints, adjusted MX names.
    To make it easier to assign footprints, I added the U measurement to each key in the beginning of the name (MX_xU_KeyName).
    [mini-65.sch]
2020-07-22 Assigned the last of the footprints
    Step before starting on the PCB. All footprints have been added.
    [mini-65.sch]
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2020-10-16 Added some libraries, to try to add JST connector
    [mini-65.kicad_pcb, mini-65.sch]
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2020-10-19 Laid out most of the MCU + JST connector
    Still have to finish up the ICSP header and reset switch and clean up some of the component placement and wiring.
    [mini-65.kicad_pcb, mini-65.sch]
2020-10-20 Made most of the matrix, one issue left
    Unfortunately I didn't account for ROW1, meaning I didn't use one of the input pins.
    Still have to connect ROW1, now using the left over input pin.
    [mini-65.kicad_pcb, mini-65.sch]
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2020-10-22 Routed the MCU and the components around it
    [mini-65.kicad_pcb, mini-65.sch]
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2020-10-22 Routed up all the cols/rows, properly this time
    [mini-65.kicad_pcb, mini-65.sch]
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2020-10-22 Added the cols/rows to the MCU in the sch
    [mini-65.sch]
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2020-11-25 moved MCU left
    havent attached all routes yet
    [mini-65.kicad_pcb]
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2021-03-30 Revert "Added new type C symbol to schematic"
    This reverts commit 1bda37eaa5b653feb19e23a5acef818b3a9bd8ba.
    [mini-65.sch]
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2021-03-31 Wired up the ESD chip and placed everything in the right place
    [mini-65.kicad_pcb, mini-65.sch]
2021-04-01 Footprints assigned to schematic, step before changing the PCB up.
    [mini-65.sch]
2021-04-20 USB Type C schematic library added
    Edited the nicer looking Type C symbol to support the Type C footprint
    [mini-65.kicad_pcb, mini-65.sch]
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2021-04-23 Route most col/row traces
    Some col/row lines left, have to move up the MCU still.
    [mini-65.kicad_pcb, mini-65.sch]
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2021-04-23 Added grounded screwholes to schematic/PCBq
    Still have to make sure it's grounded on all sides
    [mini-65.kicad_pcb, mini-65.sch]
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2021-04-25 Rerouted +5V wire and placed fuse on the other side
    [mini-65.kicad_pcb]
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2021-04-27 Tweaked the MX footprints to include plated holes
    [mini-65.kicad_pcb, mini-65.sch]
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2021-05-29 step before flipping all diodes
    [mini-65.kicad_pcb]
2021-05-31 Diodes in different place, row traces mostly ran.
    [mini-65.kicad_pcb]
2021-05-31 ran most column/row wires. about to change schematic
    [mini-65.kicad_pcb]
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2021-06-16 minor tweaks to size of board and ground fill
    [mini-65.kicad_pcb, mini-65.sch]
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2021-06-17 USB and screw holes are in the right location
    [mini-65.kicad_pcb]
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2021-06-22 Changed ESD chip, changed Type C routing
    ESD I wanted to order was not in stock, so I changed to a different part in the schematic.
    Upon reading the datasheet, it was made clear the +5V line has t pass through the ESD chip from one side to another, not merely run a trace into and out of it from one side.
    [mini-65.kicad_pcb, mini-65.sch]
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2021-07-02 Added the logo
    Added the logo to the symbol and footprint library, then added it to the schematic and then PCB.
    If the logo has to be edited, this should be done by replacing the footprint for it.
    Next step is adding a revision/version number to the logo itself.
    Maybe some silly 'made by' type of thing too.
    [mini-65.kicad_pcb, mini-65.sch]
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2021-07-04 changed layout of schematic
    started the cleanup of the schematic, with nice lines and names above parts
    [mini-65.sch]
2021-07-05 Rearranged the schematic
    Added lines and text to the different parts of the schematic
    [mini-65.sch]
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2021-07-06 Shrunk schematic/matrix to fit on an A4 sheet
    [mini-65.sch]
2021-07-06 Rearranged the schematic to fit on an A4 sheet
    [mini-65.sch]
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2021-07-08 Made room for the GND plane between +5V/D+ & D-
    [mini-65.kicad_pcb, mini-65.sch]
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2021-07-09 Reconnected some of the traces
    After changing library locations around, some switches were disconnected in the schematic.
    Had to reconnect those.
    [mini-eLiXiVy.kicad_pcb, mini-eLiXiVy.sch]
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2021-07-09 Edited README and made the final gerber files
    [mini-eLiXiVy-B_Cu.gbl, mini-eLiXiVy-B_Mask.gbs, mini-eLiXiVy-B_SilkS.gbo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]
2021-07-11 Changed schematic's C8 100nF to 0.1uF (which are equal)
    [mini-eLiXiVy.sch]
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2021-07-13 Added OHL license silkscreen.
    Added a "Licensed under CERN-OHL-S v2" silkscreen to the PCB, as per CERN-OHL-S v2, section 2.2.9.
    [mini-eLiXiVy.kicad_pcb]
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2021-08-05 rev 1 changes
    Changed diode position for D62 and D13 (Spacebar and backspace).
    Removed the 'a' from the revision numbers, in the schematic and silkscreen art.
    [mini-eLiXiVy.kicad_pcb, mini-eLiXiVy.sch]
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2021-08-10 Tweaked silkscreen
    Changed silkscreen layer for certain keyswitches, so it can be seen from the back what locations need to be used
    [mini-eLiXiVy.kicad_pcb]
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2021-08-18 Renamed the 'releases' folder to 'gerbers' and added the rev.1 gerbers
    [mini-eLiXiVy-B_Cu.gbl, mini-eLiXiVy-B_Mask.gbs, mini-eLiXiVy-B_SilkS.gbo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]
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2021-08-23 Updated logo, refined data line traces.
    Logos have been updated to match the revision number, rev.1.1
    [mini-eLiXiVy.kicad_pcb, mini-eLiXiVy.sch]
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

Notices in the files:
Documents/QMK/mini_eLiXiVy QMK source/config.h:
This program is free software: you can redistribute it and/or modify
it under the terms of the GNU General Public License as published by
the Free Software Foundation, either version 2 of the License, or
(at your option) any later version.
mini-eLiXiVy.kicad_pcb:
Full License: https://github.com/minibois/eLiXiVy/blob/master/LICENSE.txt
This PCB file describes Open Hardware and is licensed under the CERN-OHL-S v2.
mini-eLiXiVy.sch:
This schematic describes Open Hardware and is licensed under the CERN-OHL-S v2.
